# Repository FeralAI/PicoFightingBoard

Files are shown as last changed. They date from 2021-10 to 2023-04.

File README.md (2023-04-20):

# Pico Fighting Board

Open source PCB for arcade sticks using Raspberry Pi Pico.

## Introduction

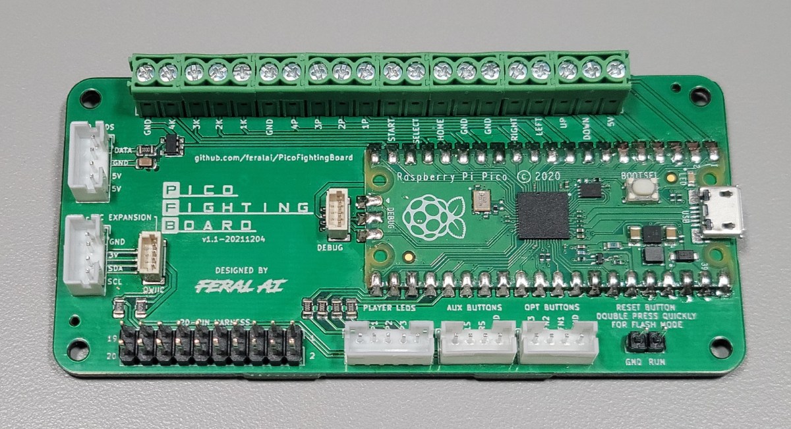
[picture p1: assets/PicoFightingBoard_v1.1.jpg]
Pico Fighting Board v1.0


They say imitation is the highest form of flattery. If that's the case then the Brook line of arcade controller boards must be blushing beet red. The Pico Fighting Board uses the same form factor and layout of the Brook PCBs to maintain compatibility with existing arcade stick cases, wiring harnesses, wire management accessories, etc.

The files for PCB production are in the [Releases](https://github.com/FeralAI/PicoFightingBoard/releases) section. The zip file contains the Gerber and drill files, which is all you'll need if you're soldering SMT components yourself. There are also `csv` files for the BOM (Bill of Materials) and component positioning for SMT assembly service.

## Firmware

The [GP2040](https://github.com/FeralAI/GP2040) gamepad firmware for Pi Pico/RP2040 has a pre-configured build for use with the Pico Fighting Board, providing support for XInput (PC, Android, Raspberry Pi, etc.), DInput (PC/PS3) and Nintendo Switch. [Go to the releases](https://github.com/FeralAI/GP2040/releases) and download the `GP2040-PicoFightingBoard.uf2`. To flash:

1. Unplug your Pico Fighting Board.
1. Hold the BOOTSEL button on the Pico and plug into your computer. A new removable drive named `RPI-RP2` should appear in your file explorer.
1. Drag and drop the `GP2040-PicoFightingBoard.uf2` file into the removable drive. This will flash the board.
1. The board should now be running the GP2040 firmware and should appear as a controller on your computer.

## Modification

If you want to modify the PCB layout you'll need the free [KiCad software](https://www.kicad.org/download/) installed. KiCad 5.1.9 was used for these instructions.

### Libraries

The [`libraries`](https://github.com/FeralAI/PicoFightingBoard/tree/main/libraries) folder contains the schematics and footprints required to work with the KiCad source files.

#### Symbols

1. From the KiCad `Preferences` menu, select `Manage Symbol Libraries...`.
1. In the `Global Libraries` tab, click the folder icon.
1. Navigate to this repository, then navigate to `libraries/RP-Pico Libraries` and select the `MCU_RaspberryPi_and_Boards.lib` file.
1. Click `OK` to finish.

#### Footprints

1. From the KiCad `Preferences` menu, select `Manage Footprint Libraries...`.
1. In the `Global Libraries` tab, click the folder icon.
1. In the `Select Libary` dialog, navigate to `libraries/RP-Pico Libraries/MCU_RaspberryPi_and_Boards.pretty` in this repository.
1. Click `OK` to confirm the folder selection.
1. Repeat the same process for the `libraries/FeralAI/FeralAI.pretty` folder.
1. Click `OK` to finish.

## Support

If you would like to discuss and issues or features with the Pico Fighting Board, please join the [OpenStick Pico Fighting Board Discord channel](https://discord.gg/ZGfT68AvpG).

## Contributions

Want to help improve the Pico Fighting Board? There are a bunch of ways to contribute!

### Pull Requests

Pull requests are welcome and encouraged for enhancements, fixes and documentation updates.

### Donations

If you'd like to make a donation to my open source work, you can

<a href="https://github.com/sponsors/FeralAI">Sponsor Feral AI on Github</a>

or

<a href="https://www.buymeacoffee.com/feralai" target="_blank">Buy Me A Coffee</a>

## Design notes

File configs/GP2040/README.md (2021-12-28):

# GP2040 Configuration for Pico Fighting Board

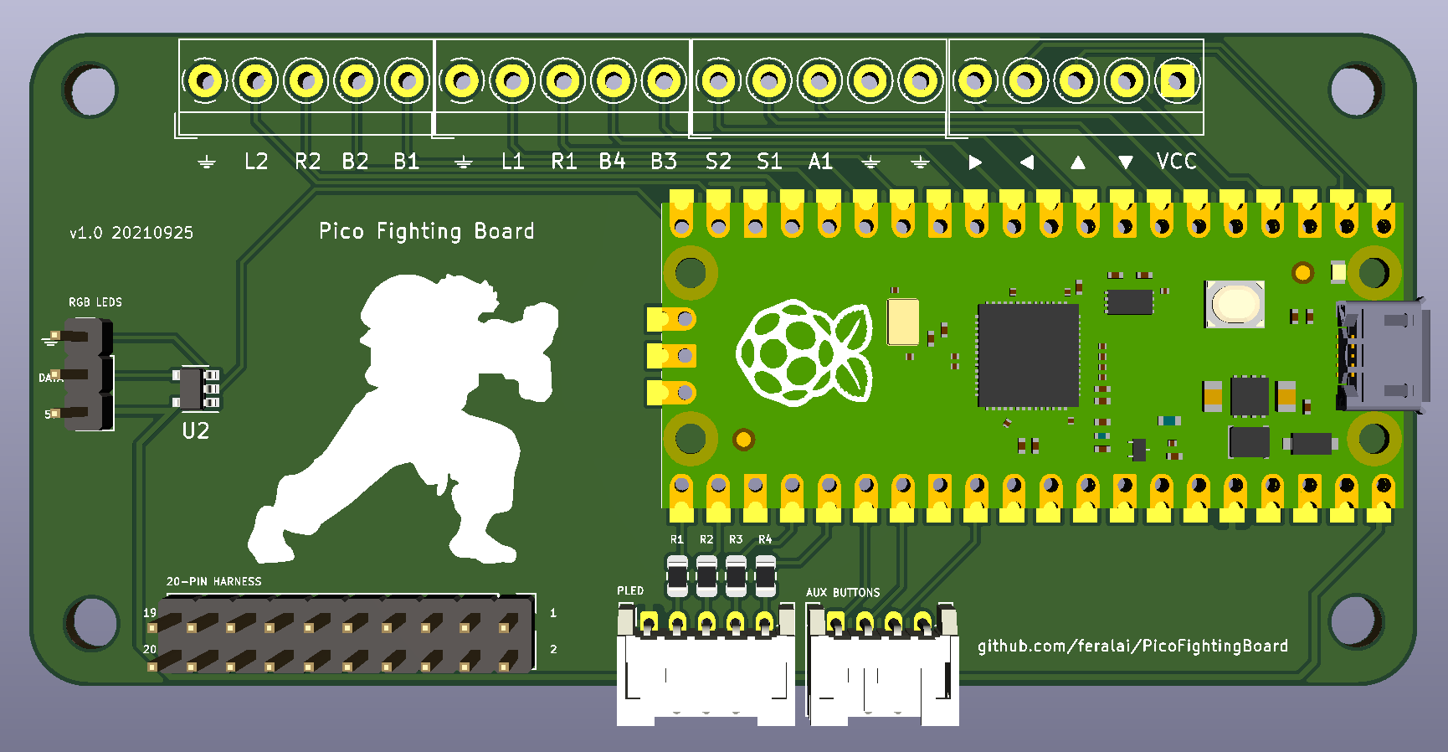
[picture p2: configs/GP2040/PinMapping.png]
Pin Mapping


Open source board based on the Brook board design: <https://github.com/FeralAI/PicoFightingBoard>. The board labels are associated with the GP2040 generic labeling. The 20-pin connector, 4-pin connector and screw terminals are button-compatible with the Brook wiring harnesses and button mappings.

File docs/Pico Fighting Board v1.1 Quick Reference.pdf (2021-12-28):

Pico Fighting Board v1.1 Quick Reference

You're the proud owner of a Pico Fighting Board! But how does your PFB work?

Button Mappings

PFB/Arcad | XInput | Switch | PS3 | DInput | GP2040
1P | X | Y | SQUARE | 1 | B3
2P | Y | X | TRIANGLE | 4 | B4
3P | RB | R | R1 | 6 | R1
4P | LB | L | L1 | 5 | L1
1K | A | B | CROSS | 2 | B1
2K | B | A | CIRCLE | 3 | B2
3K | RT | ZR | R2 | 8 | R2
4K | LT | ZL | L2 | 7 | L2
SELECT | BACK | MINUS | SELECT | 9 | S1
START | START | PLUS | START | 10 | S2
LS | LS | LS | L3 | 11 | L3
RS | RS | RS | R3 | 12 | R3
HOME | XBOX | HOME | | 13 | A1
TP | | CAPTURE | | 14 | A2

Firmware Updates
The Pico Fighting Board comes preinstalled with the latest GP2040 firmware. If you’d like to update to the latest firmware, perform the following steps:
1. Download the latest version of GP2040 for the Pico Fighting Board from https://github.com/FeralAI/GP2040/releases.
2. Unplug your Pico Fighting Board from the computer.
3. Press and hold the white BOOTSEL button on the Pico while plugging into the computer. Alternatively, if you have a button connected to the reset header you may double press the button quickly to enter flash mode.
4. Copy the GP2040-PicoFightingBoard.uf2 file to the RPI-RP2 drive that appeared when connecting the PFB.
5. Once the update is complete the Pico Fighting Board will restart and again be detected as a controller.

Input Modes
To select input mode, hold one of the following buttons when plugging in your controller:
- 1P - PS3/DInput
- 1K - Nintendo Switch
- 2K - PC/XInput

D-Pad Modes
To select the active d-pad mode, while the controller is plugged in press:
- SELECT + START + DOWN - Normal D-pad operation
- SELECT + START + LEFT - Left analog stick emulation
- SELECT + START + RIGHT - Right analog stick emulation

SOCD Modes
To select the active SOCD mode, while the controller is plugged in press:
- HOME + START + DOWN - Neutral (U+D=N, L+R=N)
- HOME + START + UP - Up Priority (U+D=U, L+R=N)
- HOME + START + LEFT - Last Input Priority

RGB LEDs
The Pico Fighting Board supports WS2812 and similar RGB LEDs. To change LED settings, press:
- SELECT + START + 1P - Next Animation
- SELECT + START + 1K - Previous Animation
- SELECT + START + 2P - Brightness Up
- SELECT + START + 2K - Brightness Down
- SELECT + START + 3P - LED Parameter Up
- SELECT + START + 3K - LED Parameter Down
- SELECT + START + 4P - Pressed Parameter Up
- SELECT + START + 4K - Pressed Parameter Down

Advanced Configuration
The GP2040 firmware has a built-in configuration app which runs from a local webserver on the Pico. To access the configuration app from a computer:
1. Hold START while plugging the controller into a computer.
2. Open a browser and navigate to http://192.168.7.1

You now have access to adjust controller settings, configure RGB LEDs, reset settings, etc.

Links
Pico Fighting Board - https://github.com/FeralAI/PicoFightingBoard
GP2040 Firmware - https://github.com/FeralAI/GP2040
GP2040 Usage Guide - https://gp2040.info/#/usage

Support
Email feral@feralai.com or join the OpenStick Discord https://discord.gg/KyQCHcjwJ2

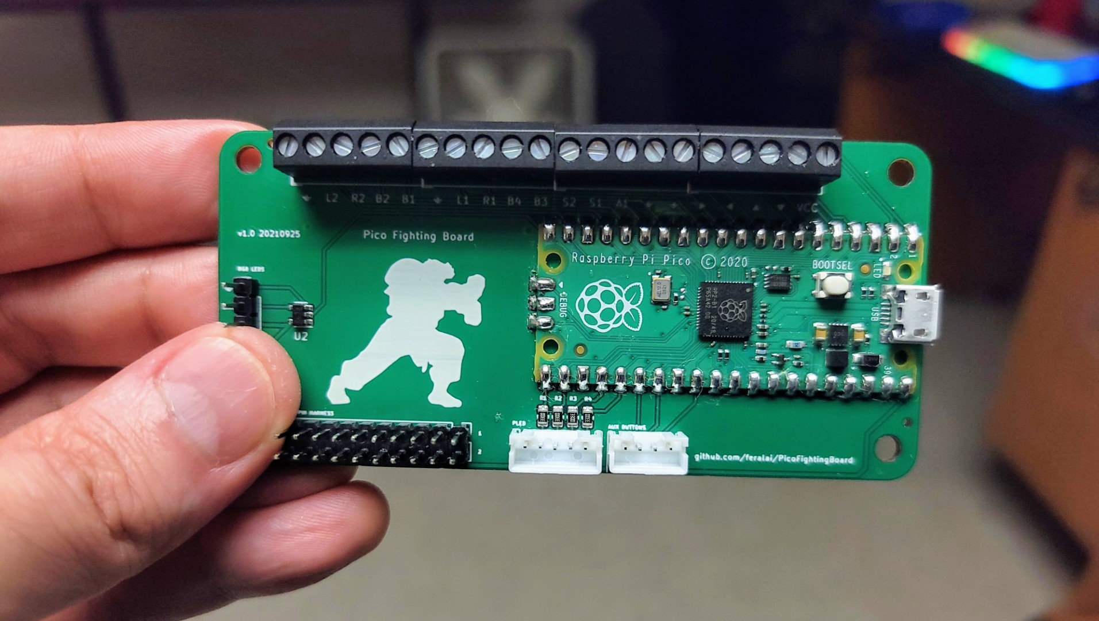
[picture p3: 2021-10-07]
assets/PicoFightingBoard_v1.0.jpg

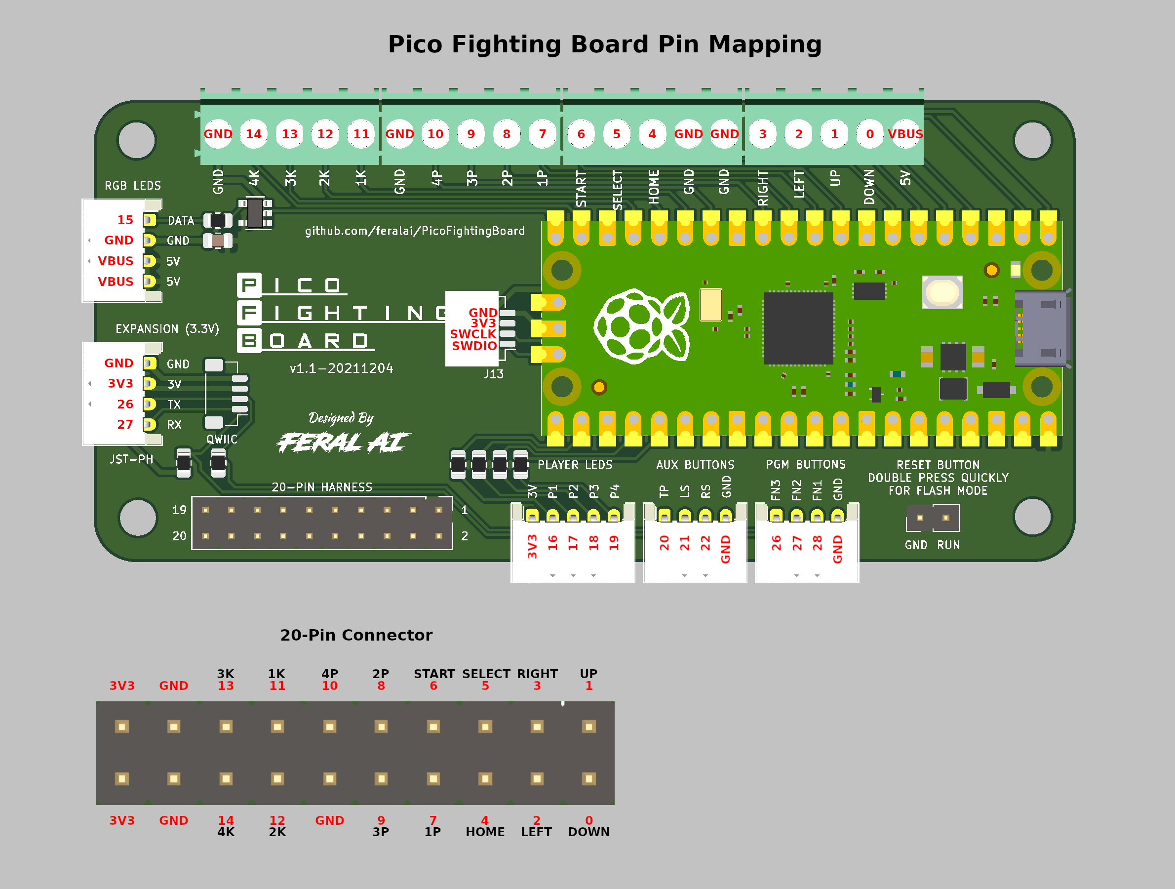
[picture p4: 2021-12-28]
boards/v1.1a/assets/pico-pin-mapping.png

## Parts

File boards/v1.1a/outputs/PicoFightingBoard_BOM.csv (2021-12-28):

Comment | Designator | Footprint | LCSC
0.1uF | C1 | Capacitor_SMD:C_0805_2012Metric | C286511
Conn_01x02_Male | J10 | Connector_JST:JST_XH_B2B-XH-A_1x02_P2.54mm_Vertical | C234182
Conn_02x10_Odd_Even | J2 | Connector_PinHeader_2.54mm:PinHeader_2x10_P2.54mm_Vertical | C492427
Conn_01x05_Male | J3 | Connector_JST:JST_PH_S5B-PH-K_1x05_P2.00mm_Vertical | C157993
Conn_01x04_Male | J1,J4,J11,J12 | Connector_JST:JST_PH_S4B-PH-K_1x04_P2.00mm_Vertical | C131334
Conn_01x04_Male | J9,J13 | Connector_JST:JST_SH_BM04B-SRSS-TB_1x04-1MP_P1.00mm_Vertical | C145961
330 | R1,R2,R3,R4,R5 | Resistor_SMD:R_0805_2012Metric | C17630
4.7k | R6,R7 | Resistor_SMD:R_0805_2012Metric | C17673
SN74LV1T34DBV | U2 | Package_TO_SOT_SMD:SOT-23-5 | C100024

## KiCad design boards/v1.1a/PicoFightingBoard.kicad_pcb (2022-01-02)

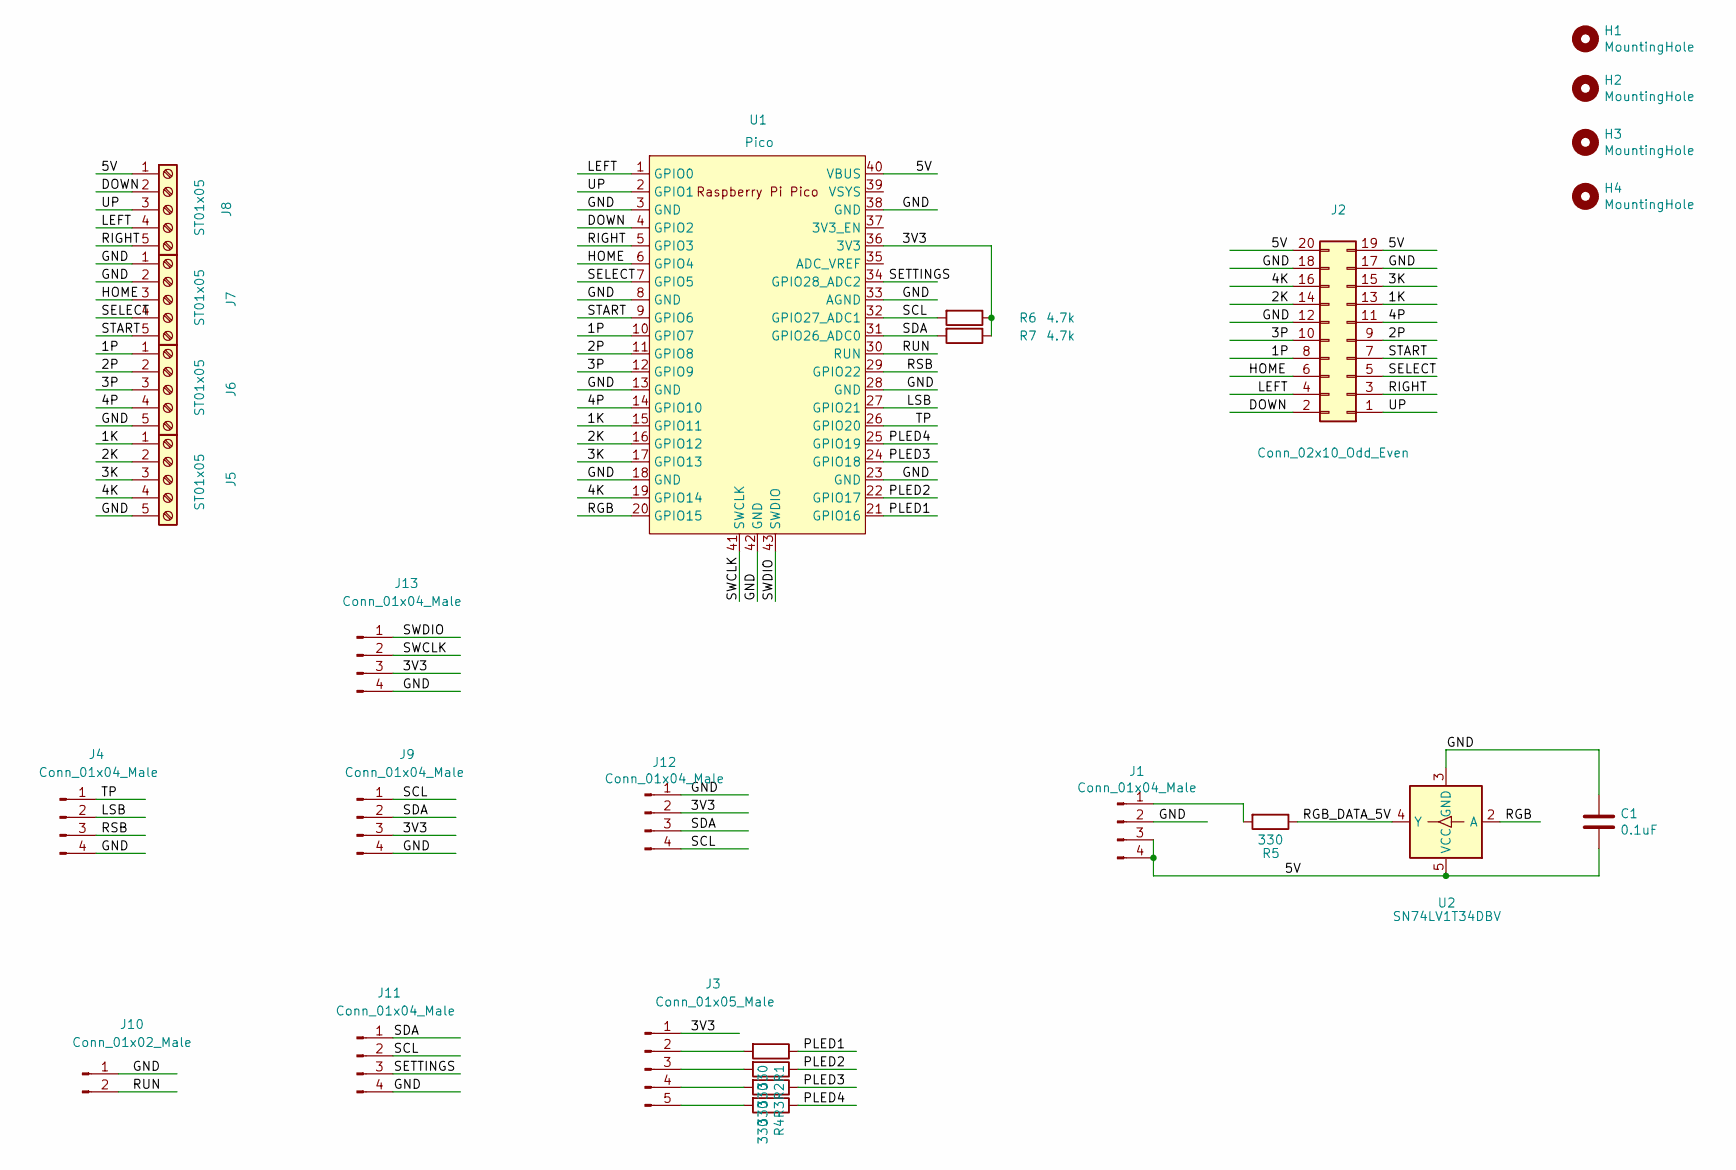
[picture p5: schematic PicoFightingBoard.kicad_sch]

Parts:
C1: 0.1uF; C_0805_2012Metric
H1, H2, H3, H4: MountingHole; MountingHole_3.5mm
J1, J4, J11, J12: Conn_01x04_Male; JST_PH_B4B-PH-K_1x04_P2.00mm_Vertical
J2: Conn_02x10_Odd_Even; PinHeader_2x10_P2.54mm_Vertical
J3: Conn_01x05_Male; JST_PH_B5B-PH-K_1x05_P2.00mm_Vertical
J5, J6, J7, J8: ST01x05; TerminalBlock_MetzConnect_Type059_RT06305HBWC_1x05_P3.50mm_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
J9, J13: Conn_01x04_Male; BOOM_SH_C145961_1x04_P1.00mm_Vertical
J10: Conn_01x02_Male; PinHeader_1x02_P2.54mm_Vertical
R1, R2, R3, R4, R5: 330; R_0805_2012Metric
R6, R7: 4.7k; R_0805_2012Metric
U1: Pico; RPi_Pico_SMD_TH_Clean
U2: SN74LV1T34DBV; SOT-23-5

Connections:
/1K: J2.13, J5.1, U1.15 (GPIO11)
/1P: J2.8, J6.1, U1.10 (GPIO7)
/2K: J2.14, J5.2, U1.16 (GPIO12)
/2P: J2.9, J6.2, U1.11 (GPIO8)
/3K: J2.15, J5.3, U1.17 (GPIO13)
/3P: J2.10, J6.3, U1.12 (GPIO9)
/3V3: J3.1, J9.3, J12.2, J13.3, R6.1, R7.1, U1.36 (3V3)
/4K: J2.16, J5.4, U1.19 (GPIO14)
/4P: J2.11, J6.4, U1.14 (GPIO10)
/5V: C1.2, J1.3, J1.4, J2.19, J2.20, J8.1, U1.40 (VBUS), U2.5 (VCC)
/DOWN: J2.2, J8.2, U1.4 (GPIO2)
/GND: C1.1, J1.2, J2.12, J2.17, J2.18, J4.4, J5.5, J6.5, J7.1, J7.2, J9.4, J10.1, J11.4, J12.1, J13.4, U1.3 (GND), U1.8 (GND), U1.13 (GND), U1.18 (GND), U1.23 (GND), U1.28 (GND), U1.33 (AGND), U1.38 (GND), U1.42 (GND), U2.3 (GND)
/HOME: J2.6, J7.3, U1.6 (GPIO4)
/LEFT: J2.4, J8.4, U1.1 (GPIO0)
/LSB: J4.2, U1.27 (GPIO21)
/PLED1: R1.1, U1.21 (GPIO16)
/PLED2: R2.1, U1.22 (GPIO17)
/PLED3: R3.1, U1.24 (GPIO18)
/PLED4: R4.1, U1.25 (GPIO19)
/RGB: U1.20 (GPIO15), U2.2 (A)
/RGB_DATA_5V: R5.1, U2.4 (Y)
/RIGHT: J2.3, J8.5, U1.5 (GPIO3)
/RSB: J4.3, U1.29 (GPIO22)
/RUN: J10.2, U1.30 (RUN)
/SCL: J9.1, J11.2, J12.4, R6.2, U1.32 (GPIO27_ADC1)
/SDA: J9.2, J11.1, J12.3, R7.2, U1.31 (GPIO26_ADC0)
/SELECT: J2.5, J7.4, U1.7 (GPIO5)
/SETTINGS: J11.3, U1.34 (GPIO28_ADC2)
/START: J2.7, J7.5, U1.9 (GPIO6)
/SWCLK: J13.2, U1.41 (SWCLK)
/SWDIO: J13.1, U1.43 (SWDIO)
/TP: J4.1, U1.26 (GPIO20)
/UP: J2.1, J8.3, U1.2 (GPIO1)
unnamed: J1.1, R5.2
unnamed: J3.2, R1.2
unnamed: J3.3, R2.2
unnamed: J3.4, R3.2
unnamed: J3.5, R4.2

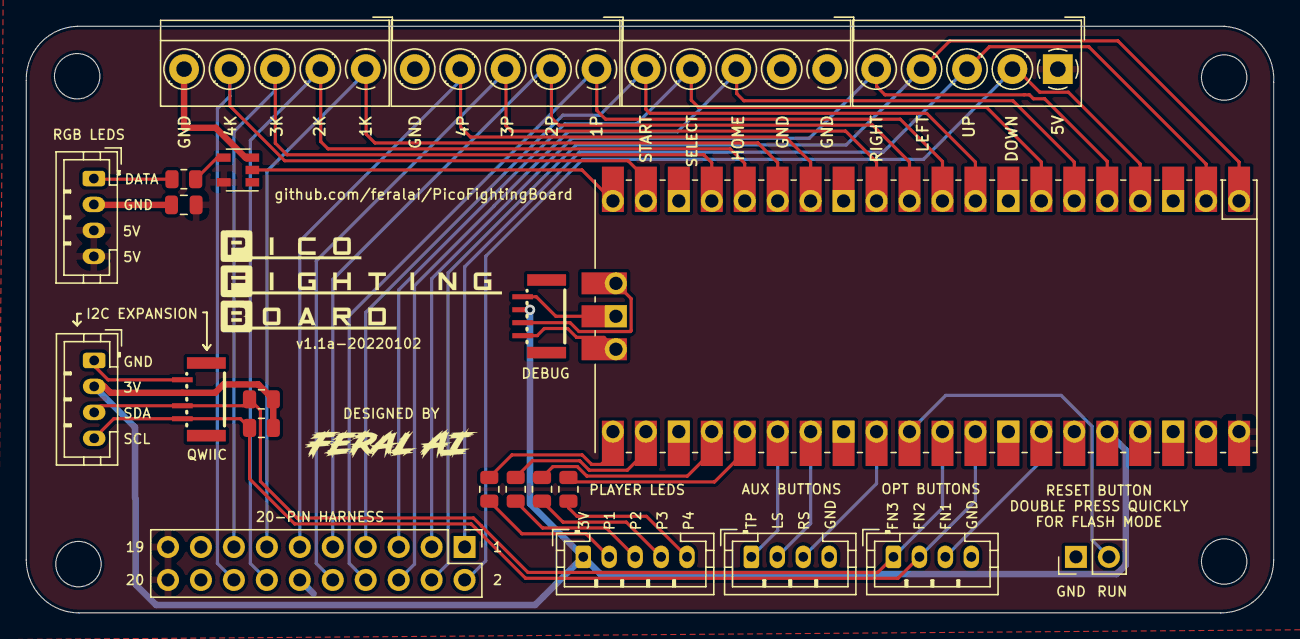
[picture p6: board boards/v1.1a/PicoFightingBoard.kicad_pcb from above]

Board: 2 copper layers, 96.1 x 45.2 mm, 27 parts (0 on the bottom side), 38 nets.

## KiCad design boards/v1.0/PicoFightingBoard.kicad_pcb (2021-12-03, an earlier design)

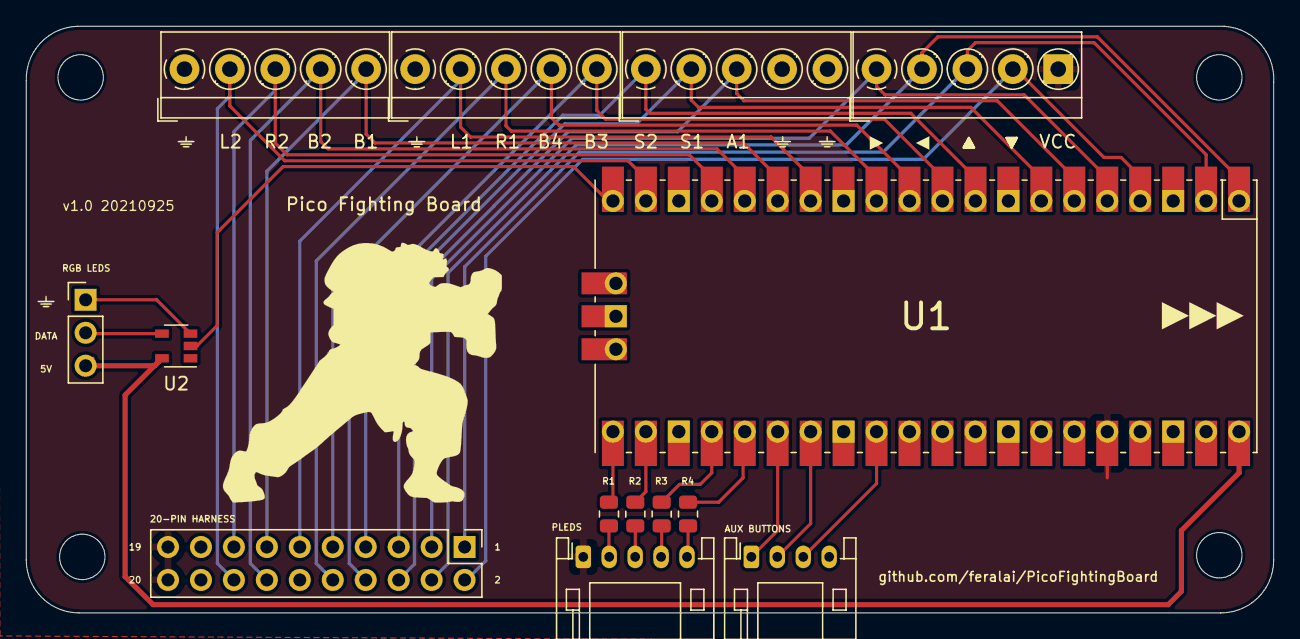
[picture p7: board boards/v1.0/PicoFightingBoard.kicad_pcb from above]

Board: 2 copper layers, 96.1 x 45.2 mm, 20 parts (0 on the bottom side), 31 nets.

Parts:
20-PIN HARNESS: Conn_02x10_Odd_Even; PinHeader_2x10_P2.54mm_Vertical
 : GS_Ground_back
 #2,  #3,  #4,  #5,  #6: GS_Ground
AUX BUTTONS: Conn_01x04_Male; JST_PH_S4B-PH-K_1x04_P2.00mm_Horizontal
J5, J6, J7, J8: Screw_Terminal_01x05; TerminalBlock_MetzConnect_Type059_RT06305HBWC_1x05_P3.50mm_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
PLEDS: Conn_01x05_Male; JST_PH_S5B-PH-K_1x05_P2.00mm_Horizontal
R1, R2, R3, R4: 330; R_0805_2012Metric
RGB LEDS: Conn_01x03_Male; PinHeader_1x03_P2.54mm_Vertical
U1: Pico; RPi_Pico_SMD_TH_Clean
U2: SN74LV1T34DBV; SOT-23-5

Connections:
/3V: 20-PIN HARNESS.19, 20-PIN HARNESS.20, J8.5, PLEDS.1, U1.36
/GND: 20-PIN HARNESS.12, 20-PIN HARNESS.17, 20-PIN HARNESS.18, AUX BUTTONS.4, J5.1, J6.1, J7.4, J7.5, RGB LEDS.1, U1.38, U2.3
unnamed: 20-PIN HARNESS.1, J8.3, U1.2
unnamed: 20-PIN HARNESS.2, J8.4, U1.4
unnamed: 20-PIN HARNESS.3, J8.1, U1.5
unnamed: 20-PIN HARNESS.4, J8.2, U1.1
unnamed: 20-PIN HARNESS.5, J7.2, U1.7
unnamed: 20-PIN HARNESS.6, J7.3, U1.6
unnamed: 20-PIN HARNESS.7, J7.1, U1.9
unnamed: 20-PIN HARNESS.8, J6.5, U1.10
unnamed: 20-PIN HARNESS.9, J6.4, U1.11
unnamed: 20-PIN HARNESS.10, J6.3, U1.12
unnamed: 20-PIN HARNESS.11, J6.2, U1.14
unnamed: 20-PIN HARNESS.13, J5.5, U1.15
unnamed: 20-PIN HARNESS.14, J5.4, U1.16
unnamed: 20-PIN HARNESS.15, J5.3, U1.17
unnamed: 20-PIN HARNESS.16, J5.2, U1.19
unnamed: PLEDS.2, R1.2
unnamed: PLEDS.3, R2.2
unnamed: PLEDS.4, R3.2
unnamed: PLEDS.5, R4.2
unnamed: AUX BUTTONS.1, U1.26
unnamed: AUX BUTTONS.2, U1.27
unnamed: AUX BUTTONS.3, U1.29
unnamed: R1.1, U1.21
unnamed: R2.1, U1.22
unnamed: R3.1, U1.24
unnamed: R4.1, U1.25
unnamed: RGB LEDS.2, U2.4
unnamed: RGB LEDS.3, U1.40, U2.5
unnamed: U1.20, U2.2

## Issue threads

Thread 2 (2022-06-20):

Corner screw holes aren't symmetric

brndd, 2022-06-20:
I don't know if this is intentional, but it seems like the corner screw holes are slightly off-kilter (on the order of 0.1-0.2 mm in various directions). This made it a little bit annoying to 3D print a stand for the board.

FeralAI, 2023-04-20:
Not by design, just a newb doing work in KiCad 😁

I don't plan to update the design, but if there is a PR with fixes I'm glad to review and merge.

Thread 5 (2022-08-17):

Is everything ok?

Xcl4m4t10n, 2022-08-17:
Hello! Just saw that you shut down the shop and nobody is able to reach you. Just not about the Pico FightingBoard but I hope you are ok.

sumonado, 2022-08-17:
I hope you are ok too! (**+1**)

eobet, 2022-09-01:
Same!

Both FeralAI and Daemonbite disappeared without a word. I hope it's just supply chain issues and not something else.

FeralAI, 2023-04-20:
Hello and thank you for your concern. Sorry to have disappeared, I was dealing with health issues. I'm back doing some work on my Github projects and the [GP2040-CE](https://github.com/OpenStickCommunity/GP2040-CE) fork of the original firmware. I will not be reopening the shop but will try get this repository cleaned up and stay active in the community going forward.

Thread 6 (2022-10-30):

hi feralal can you make custom arcade encoder for me ?

travmaa, 2022-10-30:
controller name Massive Magnetics

xinput(xbox360) and ps3 support, xinput default
(when plug hold button1 = xinput, hold button2 =ps3)

two real stick output (not emulated) in pcb dpad and left anolog stick
(when plug hold select = change leftstick and dpad inputs)

socd support, up priorty default (L+R=notr,up+down=up)
(when plug hold start = socd on or off)

default settings key (when plug hold start+select all default)

Buttons:
left anolog stick(l-r-u-d)
dpad (l-r-u-d)
select
start
home
a
x
y
b
lt
rt
rb
lb

1000hz report rate
Selectable debounce setting 2-4-8 ms (with button ,jumper,led etc)
Driverless

i have atmega 8
       pic16f24k50
       arduino pro micro (mega32u4)
       raspberry pi pico (rp2040)

i can pay paypal or donate ty.
sory for bad english

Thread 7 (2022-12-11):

need help with ws2812B wiring with pico fighting board v1.1

heavymitts, 2022-12-11:
Good Day All,

I need help in wiring my ws2812B to the pico fighting board v1.1. I would like to ask if you have any pictures on how you wired them on your v1.1 pico.

I also would like to ask if I am suppose to press something to turn on the LED once connected, or does it light up right away as soon it is connected to a ps4 or pc?

Thank you again.

FeralAI, 2023-04-24:
>

The JST connector on the end of the board labeled `RGB LEDS` is where you would connect your LED strip. The LED strip should have 3 wires to connect, and they will connect to the pins labeled `DATA`, `GND` and `5V` (the extra `5V` pin is for compatibility with older fightstick LED systems). If you're using a build of GP2040 or GP2040-CE for the Pico Fighting Board the LEDs should start right away. From there you can use shortcuts to modify their behavior:  https://gp2040-ce.info/#/usage?id=rgb-leds

> I couldnt understand pico fighting boards 5 volt terminal connections. there is no connections in 5v when I open it with kicad. I have to connections on my ws2812b led strip. GND, Data and 5v. And I dont know what happens if I connect these 3 pin to pico fighting board. Because 5v pin is empty on PCB, no connection any hole.

The top pour on the board is 5V. The 5V screw terminal, 5V pins on the 20-pin header, and 5V pins in the RGB connector are connected to that pour.

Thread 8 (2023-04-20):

I've created a to scale 3D model of the board and parts

multigamesystem, 2023-04-20:
Not quite sure how to contact you FaralAI but I created a to scale 3D model in CAD.  Its in .step format so its easily loaded into many CAD programs.  The intention is to aid people with designing 3D printed enclosures or CNC cut parts around your board design.

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

I've uploaded the .step file to my fork of your repo.

[https://github.com/multigamesystem/PicoFightingBoard/tree/fd67aa0f9b772f1285bba5c89ccf2695f30f03f0/Step%20file%20for%20CAD](url)

Please excuse my ignorance as I am new to GitHub contribution.

FeralAI, 2023-04-20:
Thank you. I can see this being helpful. I will pull this into the repository soon when I perform some cleanup.

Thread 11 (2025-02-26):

Pico Compatibility?

Slypty, 2025-02-26:
Wanted to say thanks a ton for creating this Project, I've built a bunch of Sticks off this design and implemented them into 3D printed Arcade Shells, everyone seems to love the PFB.

  I've always used the 4M RP2040 with castellated edges, most recently I decided to try the 16M version and some headers instead.  I flashed the RP2040 with the latest version, and for some reason I have no response at all from my stick or any buttons.  Maybe I washed the board too much, but wanted to check there's no compatibility issues with using the 16M RP2040s?  Thanks again

Slypty, 2025-03-22:
The issue is that the RP2040's I bought have a slightly different pinout.  In place of GP4 this design uses 'G' on Pins 6 and 13.  Look out for boards labelled with 'G' on them, they are tied to VSys Ground internally.  So once it's placed into the PFB, these contacts short out and make the board non-functional.   These boards have the 4-pin debugger layout at the bottom instead of the standard 3.

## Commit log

2021-12-03 Fix pin 12 ground on 20-pin connector
    [PicoFightingBoard.kicad_pcb, PicoFightingBoard.sch]
2021-12-03 WIP for v1.1
    [PicoFightingBoard.kicad_pcb, PicoFightingBoard.sch]
2021-12-05 Commit latest rev
    [PicoFightingBoard.kicad_pcb, PicoFightingBoard.sch]
2021-12-05 Almost there
    [PicoFightingBoard.kicad_pcb, PicoFightingBoard.sch]
2021-12-05 Latest v1.1 rev
    [PicoFightingBoard.kicad_pcb, PicoFightingBoard.sch]
2021-12-06 Commit output files
    [PicoFightingBoard-B_Cu.gbl, PicoFightingBoard-B_Mask.gbs, PicoFightingBoard-B_Paste.gbp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]
2021-12-11 Update v1.1 to final
    [PicoFightingBoard-B_Cu.gbl, PicoFightingBoard-B_Mask.gbs, PicoFightingBoard-B_Paste.gbp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]
2021-12-31 Add v1.1a rev
    [PicoFightingBoard-B_Cu.gbl, PicoFightingBoard-B_Mask.gbs, PicoFightingBoard-B_Paste.gbp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]
2022-01-02 Update to KiCad 6.0.0 for v1.1a board
    [PicoFightingBoard.csv, PicoFightingBoard.kicad_pcb, PicoFightingBoard.kicad_sch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]
2022-01-02 v1.1a final?!?
    [PicoFightingBoard-B_Cu.gbl, PicoFightingBoard-B_Mask.gbs, PicoFightingBoard-B_Paste.gbp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]
